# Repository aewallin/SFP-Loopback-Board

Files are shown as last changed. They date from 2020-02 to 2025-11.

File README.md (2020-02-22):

# SFP-Loopback-Board
SFP optical transciever loopback board. Connects SFP TX pins to RX pins, and provides buffered ( [ONET1191](http://www.ti.com/product/ONET1191P) )probe-outputs on SMA connectors.

See also [SFP+ timing calibration module](https://ohwr.org/project/wr-calibration/wikis/Electrical-absolute-calibration)

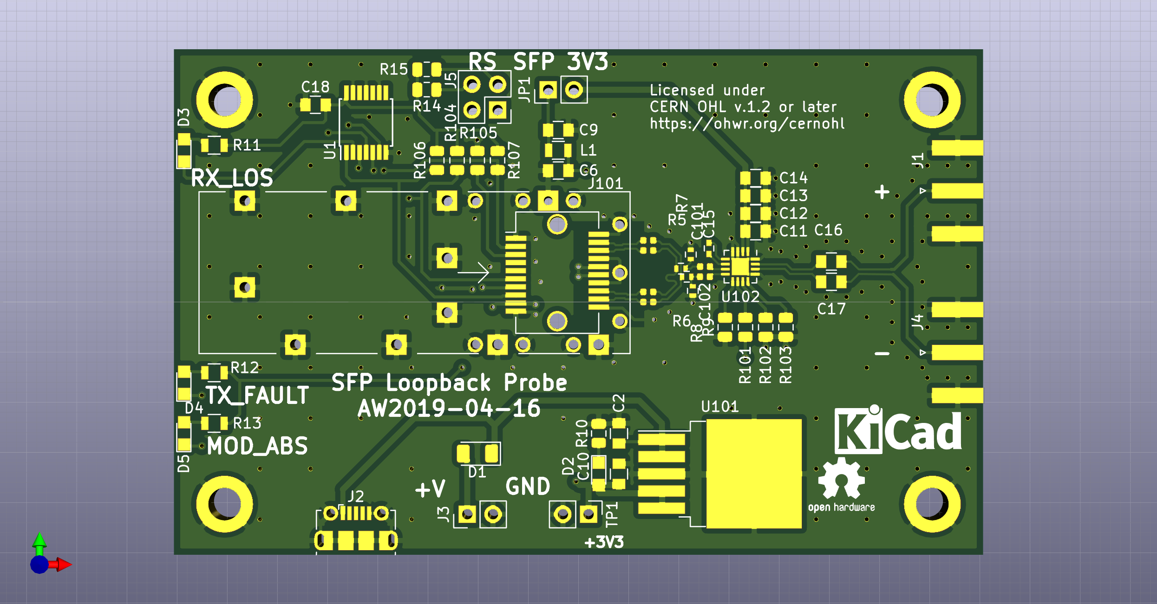
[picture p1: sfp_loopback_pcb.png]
PCB


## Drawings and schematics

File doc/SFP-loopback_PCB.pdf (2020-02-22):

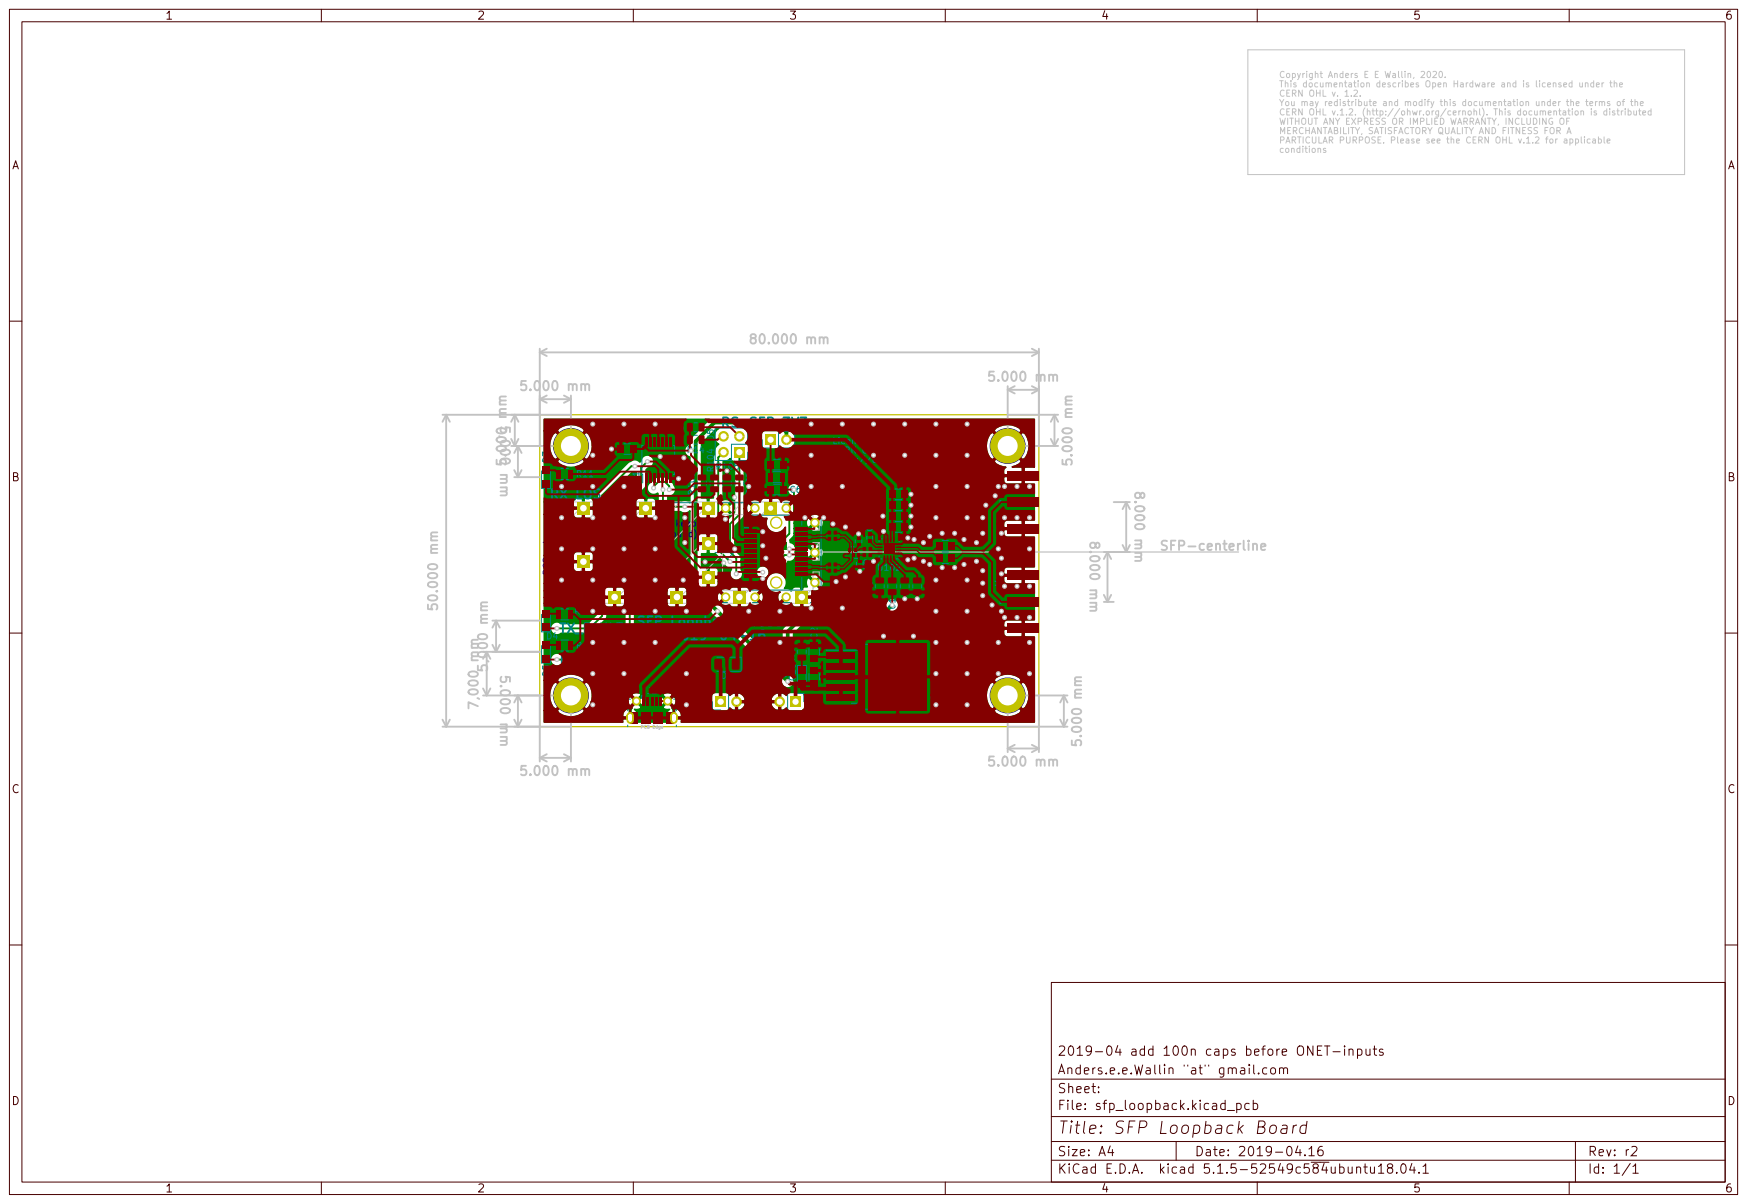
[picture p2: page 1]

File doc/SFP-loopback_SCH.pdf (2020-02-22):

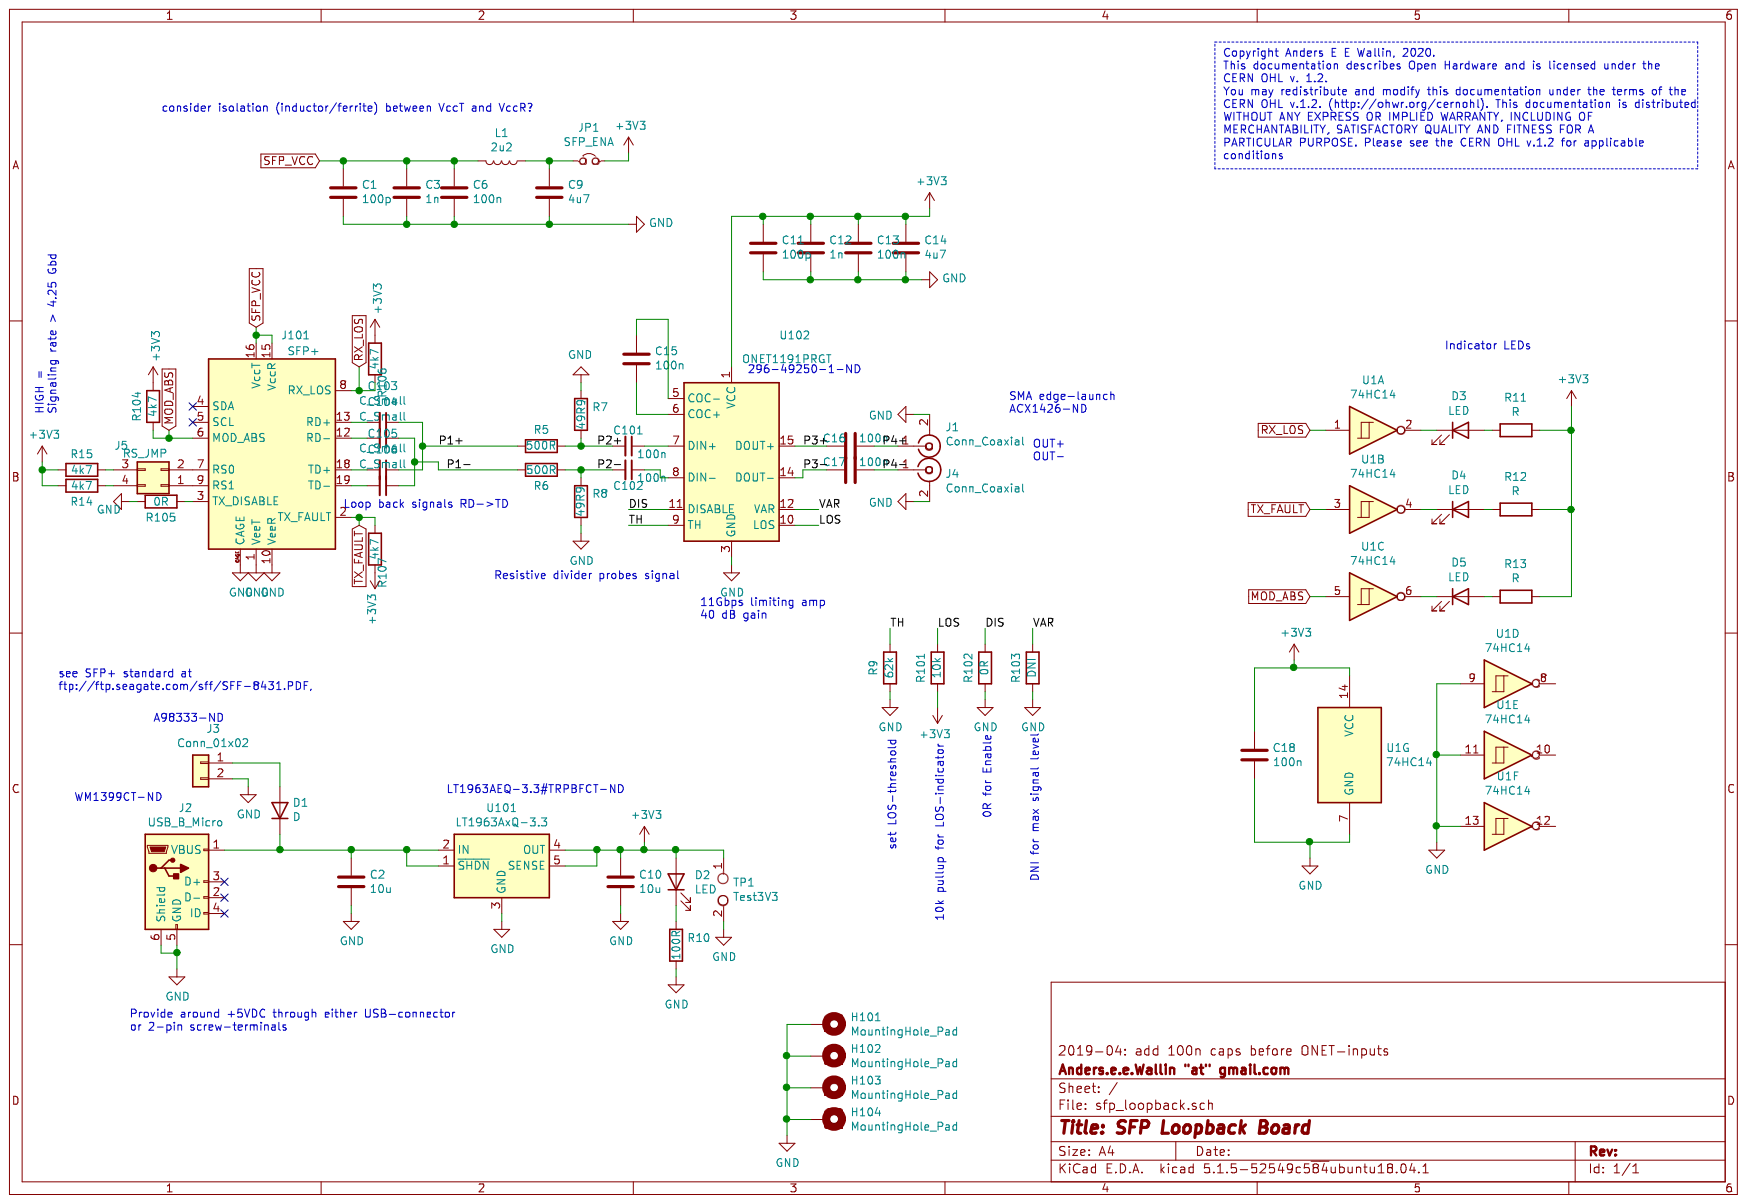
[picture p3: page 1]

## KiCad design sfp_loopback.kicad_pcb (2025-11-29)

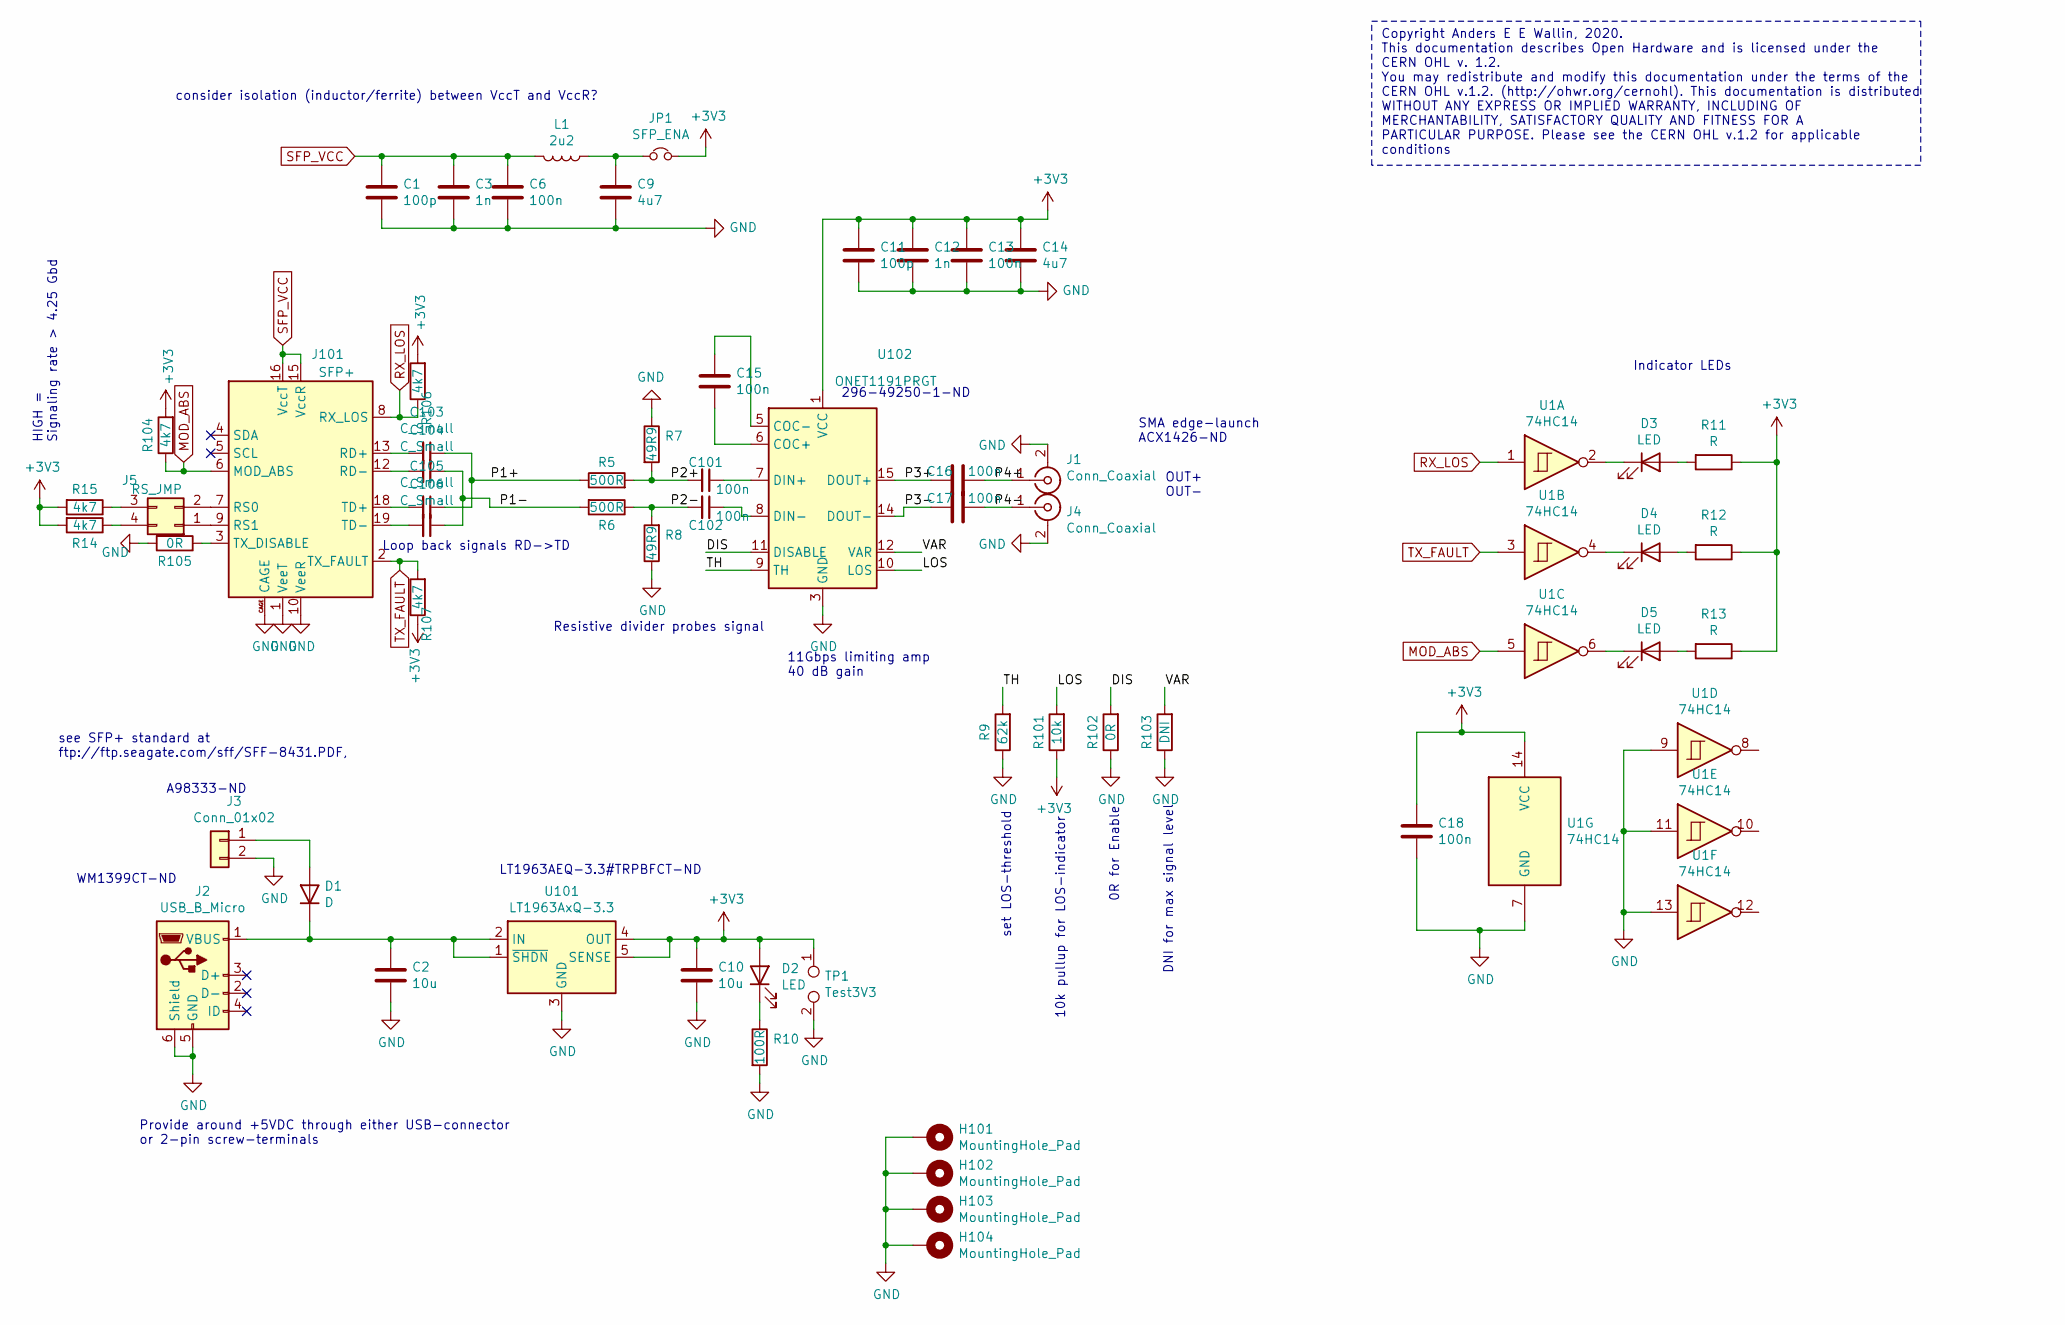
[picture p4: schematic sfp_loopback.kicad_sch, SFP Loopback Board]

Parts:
C1: 100p; C_0603
C2, C10: 10u; C_0805
C3, C12: 1n; C_0805
C6, C13, C16, C17, C18: 100n; C_0805
C9, C14: 4u7; C_0805
C11: 100p; C_0805
C15: 100n; C_0402
C101, C102: 100n; C_0402_1005Metric
C103, C104, C105, C106: C_Small; C_0402_1005Metric
D1: D; D_1206_3216Metric
D2, D3, D4, D5: LED; LED_0805
H101, H102, H103, H104: MountingHole_Pad; MountingHole_3.2mm_M3_DIN965_Pad
J1, J4: Conn_Coaxial; SMA_Amphenol_132289_EdgeMount
J2: USB_B_Micro; USB_Micro-B_Molex-105017-0001
J3: Conn_01x02; Pin_Header_Straight_1x02_Pitch2.54mm
J5: RS_JMP; Pin_Header_Straight_2x02_Pitch2.54mm
J101: SFP+; Connector_SFP_and_Cage
JP1: SFP_ENA; Pin_Header_Straight_1x02_Pitch2.54mm
L1: 2u2; L_0805
R5, R6: 500R; R_0402
R7, R8: 49R9; R_0402
R9: 62k; R_0805_2012Metric
R10: 100R; R_0805_2012Metric
R11, R12, R13: R; R_0805
R14, R15, R104, R106, R107: 4k7; R_0805_2012Metric
R101: 10k; R_0805_2012Metric
R102, R105: 0R; R_0805_2012Metric
R103: DNI; R_0805_2012Metric
TP1: Test3V3; Pin_Header_Straight_1x02_Pitch2.54mm
U1: 74HC14; TSSOP-14_4.4x5mm_Pitch0.65mm
U101: LT1963AxQ-3.3; TO-263-5_TabPin3
U102: ONET1191PRGT; VQFN-16-1EP_3x3mm_P0.5mm_EP1.68x1.68mm

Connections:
+3V3: C10.1, C11.2, C12.2, C13.2, C14.2, C18.1, D2.2 (A), JP1.2, R11.1, R12.1, R13.1, R14.2, R15.2, R101.1, R104.2, R106.2, R107.1, TP1.1, U1.14 (VCC), U101.4 (OUT), U101.5 (SENSE), U102.1 (VCC), U102.2 (VCC)
/DIS: R102.2, U102.11 (DISABLE)
/LOS: R101.2, U102.10 (LOS)
/P1+: C103.1, C105.1, R5.1
/P1-: C104.1, C106.1, R6.2
/P2+: C101.2, R5.2, R7.2
/P2-: C102.2, R6.1, R8.2
/P3+: C16.2, U102.15 (DOUT+)
/P3-: C17.2, U102.14 (DOUT-)
/P4+: C16.1, J1.1 (In)
/P4-: C17.1, J4.1 (In)
/TH: R9.2, U102.9 (TH)
/VAR: R103.2, U102.12 (VAR)
GND: C1.1, C2.2, C3.1, C6.1, C9.1, C10.2, C11.1, C12.1, C13.1, C14.1, C18.2, H101.1, H102.1, H103.1, H104.1, J1.2 (Ext), J2.5 (GND), J2.6 (Shield), J3.2, J4.2 (Ext), J101.1 (VeeT), J101.10 (VeeR), J101.11 (VeeR), J101.14 (VeeR), J101.17 (VeeT), J101.20 (VeeT), J101.CAGE, R7.1, R8.1, R9.1, R10.2, R102.1, R103.1, R105.2, TP1.2, U1.7 (GND), U1.9, U1.11, U1.13, U101.3 (GND), U102.3 (GND), U102.4 (GND), U102.13 (GND), U102.16 (GND), U102.17 (GND)
MOD_ABS: J101.6 (MOD_ABS), R104.1, U1.5
unnamed: C2.1, D1.1 (K), J2.1 (VBUS), U101.1 (~SHDN), U101.2 (IN)
unnamed: C9.2, JP1.1, L1.1
unnamed: C15.1, U102.6 (COC+)
unnamed: C15.2, U102.5 (COC-)
unnamed: C101.1, U102.7 (DIN+)
unnamed: C102.1, U102.8 (DIN-)
unnamed: C103.2, J101.13 (RD+)
unnamed: C104.2, J101.12 (RD-)
unnamed: C105.2, J101.18 (TD+)
unnamed: C106.2, J101.19 (TD-)
unnamed: D1.2 (A), J3.1
unnamed: D2.1 (K), R10.1
unnamed: D3.1 (K), U1.2
unnamed: D3.2 (A), R11.2
unnamed: D4.1 (K), U1.4
unnamed: D4.2 (A), R12.2
unnamed: D5.1 (K), U1.6
unnamed: D5.2 (A), R13.2
unnamed: J5.3, R15.1
unnamed: J5.4, R14.1
unnamed: J101.3 (TX_DISABLE), R105.1
unnamed: J5.2, J101.7 (RS0)
unnamed: J5.1, J101.9 (RS1)
RX_LOS: J101.8 (RX_LOS), R106.1, U1.1
SFP_VCC: C1.2, C3.2, C6.2, J101.15 (VccR), J101.16 (VccT), L1.2
TX_FAULT: J101.2 (TX_FAULT), R107.2, U1.3

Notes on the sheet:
Copyright Anders E E Wallin, 2020. This documentation describes Open Hardware and is licensed under the CERN OHL v. 1.2. You may redistribute and modify this documentation under the terms of the CERN OHL v.1.2. (http://ohwr.org/cernohl). This documentation is distributed WITHOUT ANY EXPRESS OR IMPL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
A98333-ND
SMA edge-launch ACX1426-ND
Resistive divider probes signal
HIGH = Signaling rate > 4.25 Gbd
10k pullup for LOS-indicator
OUT+ OUT-
WM1399CT-ND
11Gbps limiting amp 40 dB gain
Indicator LEDs
Loop back signals RD->TD
Provide around +5VDC through either USB-connector or 2-pin screw-terminals
0R for Enable
set LOS-threshold
LT1963AEQ-3.3#TRPBFCT-ND
DNI for max signal level
consider isolation (inductor/ferrite) between VccT and VccR?
see SFP+ standard at ftp://ftp.seagate.com/sff/SFF-8431.PDF,
296-49250-1-ND

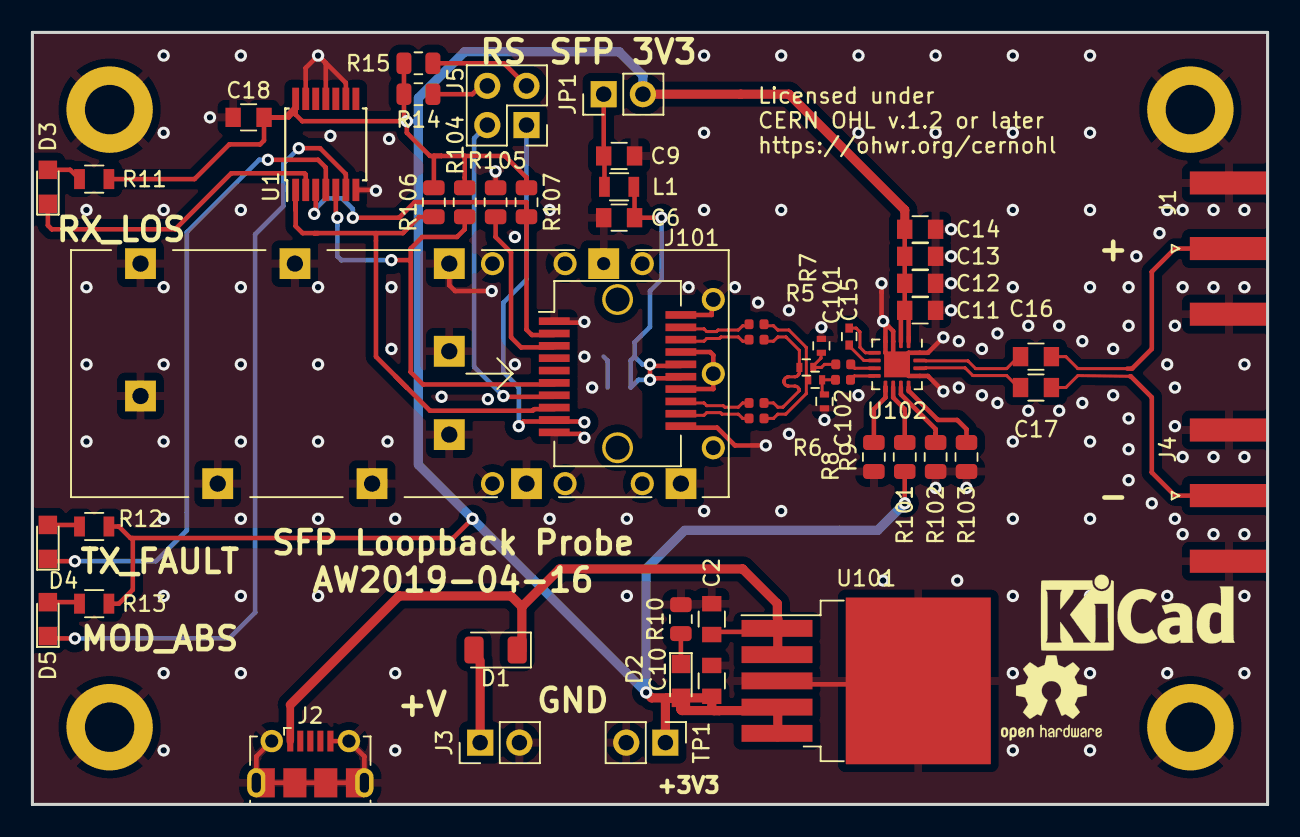
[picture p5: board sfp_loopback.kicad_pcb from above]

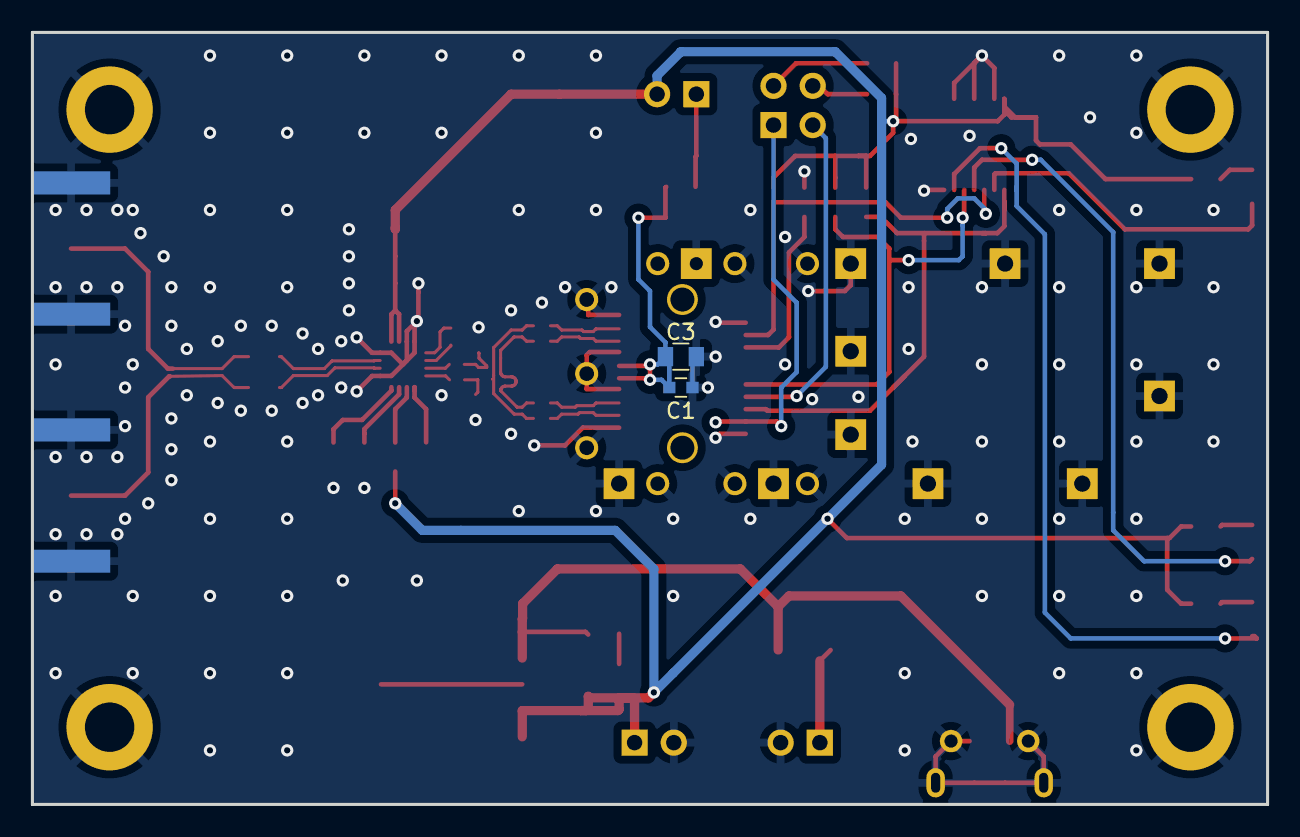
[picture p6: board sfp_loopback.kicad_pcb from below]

Board: 2 copper layers, 80.0 x 50.0 mm, 59 parts (2 on the bottom side), 41 nets.

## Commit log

2020-02-22 initial commit of files
    [sfp_loopback.kicad_pcb, sfp_loopback.sch]
2025-11-29 update to kicad9
    [sfp_loopback.kicad_pcb, sfp_loopback.kicad_sch, sfp_loopback.sch]

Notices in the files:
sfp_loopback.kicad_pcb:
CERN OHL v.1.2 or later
